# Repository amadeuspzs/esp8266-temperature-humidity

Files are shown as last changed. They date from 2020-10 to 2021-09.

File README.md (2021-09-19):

# esp8266-temperature-humidity

**Problem statement**:

> As a home-owner/renter I need to control multiple heating systems with room-by-room thermostats that I can move around for optimum measurements.

**Solution statement**:

> Hardware (ESP12F with Si7021 sensor) and software (Arduino) implementation of a WiFi MQTT temperature/humidity sensor with battery voltage monitoring and 9+ months rechargeable battery life. Designed for integration with [Home Assistant](https://www.home-assistant.io/).

See the [product website](https://amadeuspzs.github.io/esp8266-temperature-humidity/) for a summary.

Example output via Home Assistant

Example energy usage over startup and 4 measurements

## Prerequisites

1. An ESP8266 implementation like ESP-01, ESP-12F or NodeMCU
2. A <strike>DHT22 or</strike> Si7021 sensor
2. An MQTT server like [Mosquitto](https://mosquitto.org/)
3. 2.4GHz WiFi network with the ability to assign static IP addresses
4. Arduino IDE for flashing

## [Hardware](hardware/)

Tested on:

1. ESP-01 _lacks easy GPIO16 access for deep sleep_
2. ESP-12F **current preferred module**
3. NodeMCU _has power-hungry onboard components_

Tested with:

1. DHT22 _inefficient and low precision_
2. Si7021 **current preferred sensor**

Tested with:

1. 2xAA batteries _fine but unsustainable_
2. Generic JST Li-Ion battery **current preferred battery**

Tested with:

1. MCP1700 **current preferred regulator**
2. TPS62203 _high frequency switching too fiddly to implement stably_

End goal is to print the smallest PCB + battery package and 3D print a case for discrete deployment.

## [Software](software/)

Goal is to make the device last as long as possible on batteries.

## Energy performance

Current best energy usage is using the Si7021 sensor, measured using a [currentRanger](https://lowpowerlab.com/guide/currentranger/).

**Startup: `0.0789mAh`**

Startup

This includes initial connection to WiFi, sensor reading, publication, writing to RTC memory.

**Reading (no change): `0.0012mAh`**

No change

This shows the initial reading of RTC memory, sensor measurement, sleep and wake up to publish result.

**Reading (change): `0.0285mAh`**

Change

This shows the initial reading of RTC memory, sensor measurement, sleep and wake up to publish result.

**Energy estimates**

* Worst case (a reading every 10 minutes): `4.75mAh/day` this should last ~**9 months** on a 1200mAh battery.
* Better case (heuristically [50 readings a day](analysis/temperature.ipynb)): `2.19mAh/day` this should last **over a year** on a 1200mAh battery.

### Credits

* Many thanks to [Andy Bennett](http://twitter.com/databasescaling) for all the support and assistance throughout the projet
* Thanks to the [OpenEnergyMonitor Project](https://openenergymonitor.org/) for the tip on Si7021 sensor and low power inspirations.
* Thanks to the [LowPowerLab team](https://lowpowerlab.com/) for making the CurrentRanger and low power inspirations.

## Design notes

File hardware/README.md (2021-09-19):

# Hardware

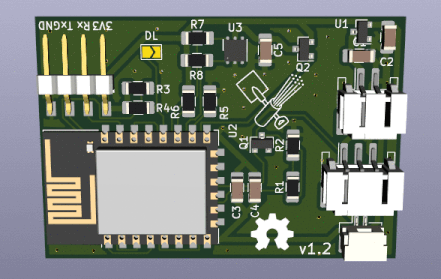
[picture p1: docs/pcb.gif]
PCB in 3D


## Battery powered

**Goal: run for 6 months+ using a battery.**

### Batteries

Device|Min voltage (V)|Stated voltage (V)|Max voltage (V)
---|---|---|---
[ESP-12F](http://wiki.ai-thinker.com/_media/esp8266/a014ps01.pdf)|3.0|3.3|3.6
[Li-Ion Cell](https://www.amazon.co.uk/XHDATA-Rechargeable-Intelligent-Protection-Environmental-BL-5C/dp/B0796L49J1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)|2.8|3.7|4.2
2 X AA Alkaline|2.8|3|3.3

Two options:

1. Regulate the Li-Ion voltage to 3.3V using e.g. [MCP1700](https://www.microchip.com/wwwproducts/en/MCP1700)
2. Run off alkaline batteries without regulator (unsustainable as not rechargeable)

##### Li-Ion cells (UK)

Battery|Cost (£)|Capacity (mAh)|Unit Cost (p/mAh)|Connector
---|---|---|---|---
[BL-5C](https://www.amazon.co.uk/XHDATA-Rechargeable-Intelligent-Protection-Environmental-BL-5C/dp/B0796L49J1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)|4.49|1500|0.30|None
[MakerFocus](https://www.ebay.co.uk/itm/4pcs-3-7V-1000mAh-Lipo-Batteries-with-Micro-JST-1-25-Plug-for-Arduino-Nodemcu/402439197613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)|3.49|1000|0.35|JST GH 1.25
[Generic](https://www.ebay.co.uk/itm/4Packs-1800mAh-3-7V-Lipo-Battery-USB-Charger-JST-Plug-for-RC-Quadcopter-Drone-UK/402483469522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)|4.75|1800|0.26|JST RCY (BEC)
**[Generic](https://www.ebay.co.uk/itm/3-7V-1200mAh-Lipo-Polymer-Rechargeable-Battery-JST-3P-PH-2-0mm-connector-603450/123751016161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)**|**2.59**|**1200**|**0.22**|**JST PH 3pin**
[Generic](https://www.ebay.co.uk/itm/3-7V-1200mAh-Lipo-rechargeable-Battery-603450-JST-1-25mm-2pin-plug-For-GPS-MP3/124254908489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)|2.00|1200|0.17|JST GH 1.25mm 2 pin
[CrazePony](https://www.amazon.co.uk/Crazepony-UK-1600mAh-battery-Connector-Quadcopter/dp/B07SPZXRWZ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)|5.50|1600|0.34|JST RCY (BEC)
[Adafruit LiPo](https://www.adafruit.com/product/1578)|6.00|500|1.20|JST PH
[Cool Components](https://coolcomponents.co.uk/products/lithium-polymer-battery-1000mah?_pos=7&_sid=3b7614679&_ss=r)|7.50|1000|0.75|JST PH
["LG" 18650](https://www.ebay.co.uk/itm/Genuine-LG-HG2-18650e-3000mAh-30A-3-7V-Rechargeable-Battery-With-Free-CASE/254800295445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)|5.49|3000|0.18|None - use case

##### Connectors

Connector|Spacing (mm)|Type|Cost (£)
---|---|---|---
[JST GH](https://www.aliexpress.com/item/33051405214.html?spm=2114.12057483.0.0.4016581aHOYzeO)|1.25|Right angle through hole|0.0009
JST RCY|
[JST PH 2pin](https://uk.farnell.com/jst-japan-solderless-terminals/b2b-ph-sm4-tb-lf-sn/connector-header-smt-2mm-2way/dp/9492534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)|2.0|Right angle PCB|0.45
**[JST PH 3pin](https://uk.farnell.com/jst-japan-solderless-terminals/b3b-ph-sm4-tb-lf-sn/connector-header-smt-2mm-3way/dp/9492542)**|**2.0**|**Right angle PCB**|**0.52**

### 3.3V Regulators

Regulator|Type|Quiescent Current (uA)|V<sub>in</sub> (V)|Max current (mA)|Package
---|---|---|---|---|---
[MCP1700](https://www.microchip.com/wwwproducts/en/MCP1700)|LDO|1.6|3.6-6|250|SOT-23
[TPS62203](https://www.ti.com/product/TPS62203)|Buck|15|3.6-6|300|SOT-23

### Sensors

Sensor|Package|Power up time (ms)|Read time (ms)|Active current (mA)|Standby current (uA)|Repeatability (RH%)|Repeatability (°C)
---|---|---|---|---|---|---|---
[DHT22](https://www.sparkfun.com/datasheets/Sensors/Temperature/DHT22.pdf)|Large|N/A|2000|1.5|50|1|0.2
[Si7021](https://www.silabs.com/documents/public/data-sheets/Si7021-A20.pdf)|DFN|18|10|0.15|0.06|0.2|0.08

Compare the current usage of both sensors (the initial section is reading RTC memory):

**DHT22:**

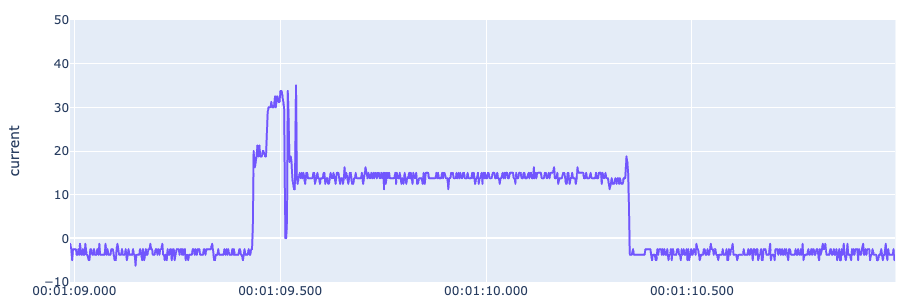
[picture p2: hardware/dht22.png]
DHT22


**Si7021:**

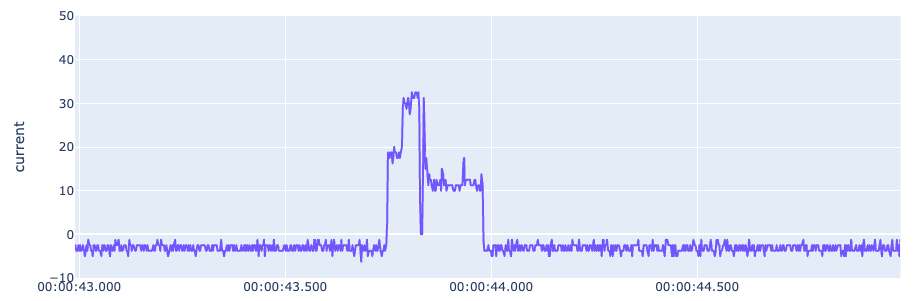
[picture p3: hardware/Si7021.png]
Si7021


The **Si7021** outperforms in both precision, accuracy, speed and current!

### Schematics

**Battery powered MCP1700 Si7021:**

Battery powered Si7021 v1.3

PCB

**Mains powered DHT22:**

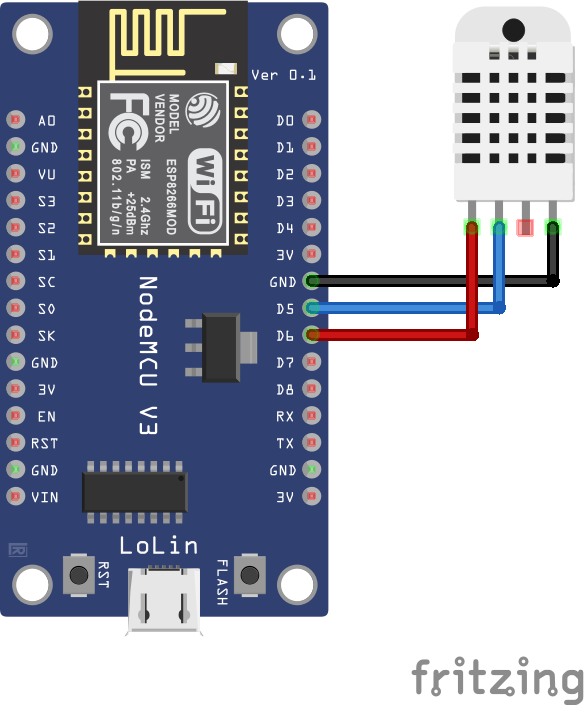
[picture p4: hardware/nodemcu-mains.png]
Mains powered DHT22


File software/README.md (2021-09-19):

# Software

Flashed using the Arduino IDE and Board Manager URL: http://arduino.esp8266.com/stable/package_esp8266com_index.json with "Generic ESP8266 Module" board.

There are two versions:

1. Mains-powered sketch
2. Battery-powered sketch, pushing every 10 minutes

Both require an MQTT server.

Additionally there is an [ADC calibration sketch](adc-calibration/) for more accurate battery health measurements.

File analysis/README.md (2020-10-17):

# Analysis

Various tools to analyse elements of the project with the aim to:

1. Maximise power efficiency
2. Understand heat transfer between rooms

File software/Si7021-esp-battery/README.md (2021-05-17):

# Battery-powered sketch

Low power version based on https://www.bakke.online/index.php/2017/05/21/reducing-wifi-power-consumption-on-esp8266-part-1/ and https://blog.voneicken.com/projects/low-power-wifi-intro/.

`WAKE_RF_DEFAULT` workaround thanks to https://github.com/esp8266/Arduino/issues/3072#issuecomment-288530130

Flashed using the Arduino IDE and Board Manager URL http://arduino.esp8266.com/stable/package_esp8266com_index.json with "Generic ESP8266 Module" board.

## Features

1. Uses `WAKE_RF_DISABLED` in deep sleep to shut down RF when not needed
2. Stores `BSSID` after connection to save scan time
3. Checks every X (10) minutes for change in temperature
4. If temperature change detected, checks for changes in humidity and Vbatt
5. Reboots with `WAKE_RF_DEFAULT` and publishes changes

## Flowchart

Flowchart

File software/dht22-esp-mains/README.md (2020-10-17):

# Mains-powered sketch

Features:

* USB powered via NodeMCU board
* Only publishes changes >= repeatability of sensor
* Checks every [X] minute(s)

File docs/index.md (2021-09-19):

# Low power WiFi temperature/humidity sensor

## Features

* 9 months+ runtime on a 1200mAh Li-Ion battery
* Highly accurate Si7021 temperature and humidity sensor
* Physical case with low impact on temperature (<0.05&deg;C)
* MQTT integration with e.g. Home Assistant directly over WiFi
* PH2, PH3 and GH2 connectors for range of Li-Ion batteries
* POGO programming header for quick flashing
* Battery voltage measurement for power management
* [Technical details available on Github](https://github.com/amadeuspzs/esp8266-temperature-humidity/)

## PCB

* No through-hole components for easy stacking on top of Li-Ion battery
* Two-layer, 50 mm x 34 mm
* [KiCad files](https://github.com/amadeuspzs/esp8266-temperature-humidity/tree/master/hardware/esp12f-si7021/)
* [Gerber files](https://github.com/amadeuspzs/esp8266-temperature-humidity/tree/master/hardware/esp12f-si7021/gerber)
* [Partial BoM](https://github.com/amadeuspzs/esp8266-temperature-humidity/tree/master/hardware/esp12f-si7021/esp12f-si7021_bom.csv)

## Software

* [Arduino files](https://github.com/amadeuspzs/esp8266-temperature-humidity/tree/master/software/Si7021-esp-battery)
* Update `config.h` with your settings
* Fine-tune `vbatt_calibration` for accurate battery voltage measurements

## Case

* 3D printed case: [STL](https://github.com/amadeuspzs/esp8266-temperature-humidity/tree/master/hardware/case_with_lid.stl), [SCAD](https://github.com/amadeuspzs/esp8266-temperature-humidity/tree/master/hardware/case_with_lid.scad)

Render of 3D printed case2

Photo of 3D printed case1

* Analysis shows latest case design (`case2`) only impacts temperature readings by `0.05`&deg;C, less than the sensor repeatability (`0.08`&deg;C):

Analysis of case impact

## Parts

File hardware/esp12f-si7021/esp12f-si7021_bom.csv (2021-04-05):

Reference | Quantity | Value | Footprint | Datasheet
C1 C2 | 2 | 1uF | Capacitor_SMD:C_1206_3216Metric_Pad1.42x1.75mm_HandSolder | ~
C3 C5 | 2 | 0.1uF | Capacitor_SMD:C_1206_3216Metric_Pad1.42x1.75mm_HandSolder | ~
C4 | 1 | 10uF | Capacitor_SMD:C_1206_3216Metric_Pad1.42x1.75mm_HandSolder | ~
J1 | 1 | JST PH3 | Connector_JST:JST_PH_S3B-PH-SM4-TB_1x03-1MP_P2.00mm_Horizontal | ~
J2 | 1 | UART | kicad-custom:PinHeader_1x4_P2.54mm_Horizontal_SMD | ~
J3 | 1 | JST PH2 | Connector_JST:JST_PH_S2B-PH-SM4-TB_1x02-1MP_P2.00mm_Horizontal | ~
J4 | 1 | JST GH2 | Connector_JST:JST_GH_SM02B-GHS-TB_1x02-1MP_P1.25mm_Horizontal | ~
JP1 | 1 | Download | Jumper:SolderJumper-2_P1.3mm_Open_TrianglePad1.0x1.5mm | ~
Q1 Q2 | 2 | BSS84 | Package_TO_SOT_SMD:SOT-23 | http://assets.nexperia.com/documents/data-sheet/BSS84.pdf
R1 | 1 | 330K | Resistor_SMD:R_1206_3216Metric_Pad1.42x1.75mm_HandSolder | ~
R2 | 1 | 100K | Resistor_SMD:R_1206_3216Metric_Pad1.42x1.75mm_HandSolder | ~
R3 R4 R5 R6 R7 R8 | 6 | 10K | Resistor_SMD:R_1206_3216Metric_Pad1.42x1.75mm_HandSolder | ~
U1 | 1 | MCP1700-3302E_SOT23 | Package_TO_SOT_SMD:SOT-23 | http://ww1.microchip.com/downloads/en/DeviceDoc/20001826D.pdf
U2 | 1 | ESP-12F | RF_Module:ESP-12E | http://wiki.ai-thinker.com/_media/esp8266/esp8266_series_modules_user_manual_v1.1.pdf
U3 | 1 | Si7021-A20 | Package_DFN_QFN:DFN-6-1EP_3x3mm_P1mm_EP1.5x2.4mm | https://www.silabs.com/documents/public/data-sheets/Si7021-A20.pdf

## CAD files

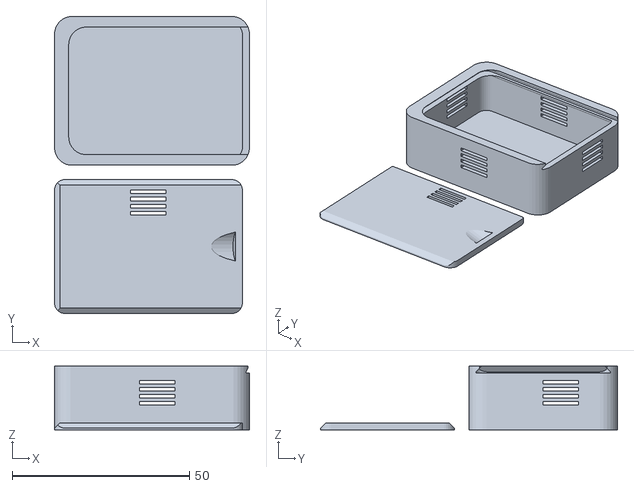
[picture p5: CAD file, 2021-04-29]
hardware/case_with_lid.stl
55.0 x 83.8 x 18.0

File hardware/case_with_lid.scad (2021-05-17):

// Remixed from https://www.thingiverse.com/thing:189264
// Todo: the rotation of the lid makes the lid vent alignment hard-coded; if you
// change the size of the box the vent won't necessarily remain aligned

wallThickness=2;

pcb_w = 34;   // PCB width
pcb_l = 50; // PCB length
pcb_h = 8; // PCB height, assembled
batt_w = 38;  // Battery width
batt_l = 51;  // Battery length
batt_h = 6;  // Battery height
overall_w = max(batt_w, pcb_w) + 2*wallThickness;
overall_l = max(batt_l, pcb_l) + 2*wallThickness;
overall_h = batt_h + pcb_h + 2*wallThickness;

itemsShown="both"; // [both,box,lid]
boxLength=overall_l;
boxWidth=overall_w;
boxHeight=overall_h;
cornerRadius=5;
bottomThickness=2;
lidThickness=2;
lidClearance=0.2;
lidEdgeThickness=0.5;
// Notch in the lid
withNotch=true; //[true:false]

sensor_pos_x = 24; // Sensor position
sensor_pos_lid_x = (overall_l - 1.5*sensor_pos_x) + wallThickness + lidEdgeThickness;

/* [Global] */
if (itemsShown=="box") showBox();
if (itemsShown=="lid") showLid();
if (itemsShown=="both"){showBox();showLid();}

module showLid(){
	translate ([0, -2*wallThickness, 0])
	roundBoxLid(l=boxLength-wallThickness,
				w=boxWidth-2*wallThickness-lidClearance,
				h=lidThickness,
				et=lidEdgeThickness,
				r=cornerRadius-wallThickness,
				notch=withNotch);
}

module showBox(){
	round_box(l=boxLength,
			  w=boxWidth,
			  h=boxHeight,
			  bt=bottomThickness,
			  wt=wallThickness,
			  lt=lidThickness,
			  r=cornerRadius);
}

module round_box(l=40,w=30,h=30,bt=2,wt=2,lt=2,r=5,){
	difference() {
		round_cube(l=l,w=w,h=h-lt,r=r);
		translate ([wt, wt, bt])
		round_cube(l=l-wt*2,w=w-wt*2,h=h,r=r-wt);
        // air holes
        translate([sensor_pos_x,0,7]) cube([10,3,1]);
        translate([sensor_pos_x,0,9]) cube([10,3,1]);
        translate([sensor_pos_x,0,11]) cube([10,3,1]);
        translate([sensor_pos_x,0,13]) cube([10,3,1]);
        translate([sensor_pos_x,boxWidth-(2*wallThickness),7]) cube([10,5,1]);
        translate([sensor_pos_x,boxWidth-(2*wallThickness),9]) cube([10,5,1]);
        translate([sensor_pos_x,boxWidth-(2*wallThickness),11]) cube([10,5,1]);
        translate([sensor_pos_x,boxWidth-(2*wallThickness),13]) cube([10,5,1]);
        translate([-wallThickness,boxWidth/2,7]) cube([5,10,1]);
        translate([-wallThickness,boxWidth/2,9]) cube([5,10,1]);
        translate([-wallThickness,boxWidth/2,11]) cube([5,10,1]);
        translate([-wallThickness,boxWidth/2,13]) cube([5,10,1]);
        translate([boxLength-wallThickness,boxWidth/2,7]) cube([5,10,1]);
        translate([boxLength-wallThickness,boxWidth/2,9]) cube([5,10,1]);
        translate([boxLength-wallThickness,boxWidth/2,11]) cube([5,10,1]);
        translate([boxLength-wallThickness,boxWidth/2,13]) cube([5,10,1]);
	}


	//use two box rims. one to make a slope to support the lid
	roundBoxRim();
	translate ([0, 0, -wt]) roundBoxRim();
}

module roundBoxRim(l=boxLength,
				   w=boxWidth,
				   h=boxHeight,
				   et=lidEdgeThickness,
				   r=cornerRadius,
				   wt=wallThickness,
				   lt=lidThickness){
	difference() {
		translate ([0, 0, h-lt])
		round_cube(l=l,w=w,h=lt,r=r);
		translate ([wt+lt,wt+lt-et*2,h-lt-0.1])
		round_cube(l=l*2,w=w-2*(wt+lt)+4*et,h=lt+0.2,r=r-wt+lt);

		//subtract out a lid to make the ledge
		translate ([wt, w-wt, h-lt-0.1])
		roundBoxLid(l=l*2,w=w-2*wt,h=lt+0.1,wt=wt,t=lt,et=0.5,r=r-wt,notch=false);
	}
}

module roundBoxLid(l=40,w=30,h=3,wt=2,t=2,et=0.5,r=5,notch=true){
	translate ([l, 0, 0])
	rotate (a = [0, 0, 180])

	difference(){

		round_cube(l=l,w=w,h=h,t=t,r=r);

		translate ([-1, 0, et]) rotate (a = [45, 0, 0])  cube (size = [l+2, h*2, h*2]);
		translate ([-1, w, et]) rotate (a = [45, 0, 0])  cube (size = [l+2, h*2, h*2]);
		translate ([l, -1, et]) rotate (a = [45, 0, 90]) cube (size = [w+2, h*2, h*2]);
		if (notch==true){
			translate([2,w/2,h+0.001]) thumbNotch(10/2,72,t);
		}
        translate([sensor_pos_lid_x,wallThickness+1,-lidThickness]) cube([10,1,lidThickness*3]);
        translate([sensor_pos_lid_x,wallThickness+3,-lidThickness]) cube([10,1,lidThickness*3]);
        translate([sensor_pos_lid_x,wallThickness+5,-lidThickness]) cube([10,1,lidThickness*3]);
        translate([sensor_pos_lid_x,wallThickness+7,-lidThickness]) cube([10,1,lidThickness*3]);
	}



}

module thumbNotch(
	thumbR=12/2,
	angle=72,
	notchHeight=2){

	size=10*thumbR;

	rotate([0,0,90])
	difference(){
		translate([0,
					(thumbR*sin(angle)-notchHeight)/tan(angle),
					 thumbR*sin(angle)-notchHeight])
		rotate([angle,0,0])
		cylinder(r=thumbR,h=size,$fn=30);

		translate([-size,-size,0])
		cube(size*2);
	}
}

module round_cube(l=40,w=30,h=20,r=5,$fn=30){
	hull(){
		translate ([r, r, 0]) cylinder (h = h, r=r);
		translate ([r, w-r, 0]) cylinder (h = h, r=r);
		translate ([l-r,w-r, 0]) cylinder (h = h, r=r);
		translate ([l-r, r, 0]) cylinder (h = h, r=r);
	}
}

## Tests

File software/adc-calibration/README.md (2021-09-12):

# ADC calibration

The ESP12F (esp8266) ADC has a built-in voltage reference of ~1.0V.

The circuit contains a voltage divider to convert a maximum 4.2V input (LiPo max voltage) to 1.0V.

The resulting measurement is used to report battery voltage via MQTT.

Both the ADC voltage reference and voltage divider values will vary from component to component.

The stock code assumes an ideal value for both:

```arduino
// Ideal ADC and voltage divider behaviour
// is 4.2/1024.0
// For accurate battery voltage measurements
// use an accurate voltage input, measure ADC
// and replace values below (assumes linear response)
#define vbatt_calibration 4.2/1024.0
```

ie. for a 4.2V input, an ADC reading of 1024.

In reality, you will want to use a known voltage, measure the ADC value and update `vbatt_calibration` to match.

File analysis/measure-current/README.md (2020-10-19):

# Measure Current

1. [Adafruit INA260 board](https://www.adafruit.com/product/4226)
2. Sparkfun Pro Micro (32U4), serial output saving to `csv`
3. [Jupyter Notebook](measure-current.ipynb)

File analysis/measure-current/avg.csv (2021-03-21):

Timestamp | Amps
2021-02-22 12:08:58.410521 | 2.659e-05
2021-02-22 12:08:58.411098 | 3.626e-05
2021-02-22 12:08:58.411588 | 3.949e-05
2021-02-22 12:08:58.412006 | 4.392e-05
2021-02-22 12:08:58.412436 | 3.949e-05
2021-02-22 12:08:58.412718 | 3.022e-05
2021-02-22 12:08:58.413000 | 2.901e-05
2021-02-22 12:08:58.413251 | 2.901e-05
2021-02-22 12:08:58.413499 | 2.7e-05
2021-02-22 12:08:58.413742 | 2.458e-05
2021-02-22 12:08:58.414354 | 2.377e-05
2021-02-22 12:08:58.414681 | 2.982e-05
2021-02-22 12:08:58.414895 | 3.223e-05
2021-02-22 12:08:58.415414 | 2.901e-05
2021-02-22 12:08:58.415779 | 2.861e-05
2021-02-22 12:08:58.416037 | 2.821e-05
2021-02-22 12:08:58.416561 | 3.183e-05
2021-02-22 12:08:58.416849 | 3.062e-05
2021-02-22 12:08:58.417328 | 2.982e-05
2021-02-22 12:08:58.417609 | 3.143e-05
2021-02-22 12:08:58.417932 | 3.264e-05
2021-02-22 12:08:58.418476 | 3.103e-05
2021-02-22 12:08:58.418766 | 2.941e-05
2021-02-22 12:08:58.419393 | 2.941e-05
2021-02-22 12:08:58.419754 | 2.901e-05
2021-02-22 12:08:58.420023 | 3.022e-05
2021-02-22 12:08:58.420528 | 2.982e-05
2021-02-22 12:08:58.420854 | 2.941e-05
2021-02-22 12:08:58.421329 | 2.78e-05
2021-02-22 12:08:58.421782 | 2.74e-05
2021-02-22 12:08:58.422524 | 2.458e-05
2021-02-22 12:08:58.422875 | 2.538e-05
2021-02-22 12:08:58.423068 | 2.377e-05
2021-02-22 12:08:58.423333 | 2.74e-05
2021-02-22 12:08:58.423578 | 3.143e-05
2021-02-22 12:08:58.423899 | 3.304e-05
2021-02-22 12:08:58.424474 | 2.941e-05
2021-02-22 12:08:58.424862 | 2.901e-05
2021-02-22 12:08:58.425378 | 3.062e-05
2021-02-22 12:08:58.425774 | 3.223e-05
2021-02-22 12:08:58.426050 | 3.143e-05
2021-02-22 12:08:58.426314 | 2.901e-05
2021-02-22 12:08:58.426645 | 3.022e-05
2021-02-22 12:08:58.427454 | 3.103e-05
2021-02-22 12:08:58.427944 | 3.143e-05
2021-02-22 12:08:58.428519 | 2.982e-05
2021-02-22 12:08:58.429022 | 2.498e-05
2021-02-22 12:08:58.429362 | 2.982e-05
2021-02-22 12:08:58.429678 | 2.861e-05
2021-02-22 12:08:58.429909 | 2.901e-05
2021-02-22 12:08:58.430217 | 2.861e-05
2021-02-22 12:08:58.430690 | 2.861e-05
2021-02-22 12:08:58.431209 | 3.264e-05
2021-02-22 12:08:58.431598 | 3.183e-05
2021-02-22 12:08:58.431981 | 3.505e-05
2021-02-22 12:08:58.432427 | 3.465e-05
2021-02-22 12:08:58.432774 | 3.183e-05
2021-02-22 12:08:58.433202 | 3.022e-05
2021-02-22 12:08:58.433432 | 2.659e-05
2021-02-22 12:08:58.433893 | 2.538e-05
2021-02-22 12:08:58.434432 | 2.538e-05
2021-02-22 12:08:58.435092 | 2.7e-05
2021-02-22 12:08:58.435550 | 2.941e-05
2021-02-22 12:08:58.435795 | 2.982e-05
2021-02-22 12:08:58.436011 | 3.183e-05
2021-02-22 12:08:58.436272 | 3.385e-05
2021-02-22 12:08:58.436470 | 3.465e-05
2021-02-22 12:08:58.436743 | 3.143e-05
2021-02-22 12:08:58.437096 | 2.982e-05
2021-02-22 12:08:58.437675 | 2.861e-05
2021-02-22 12:08:58.437981 | 2.941e-05
2021-02-22 12:08:58.438290 | 2.861e-05
2021-02-22 12:08:58.438616 | 3.022e-05
2021-02-22 12:08:58.439024 | 2.74e-05
2021-02-22 12:08:58.439483 | 2.901e-05
2021-02-22 12:08:58.439783 | 2.821e-05
2021-02-22 12:08:58.440136 | 3.223e-05
2021-02-22 12:08:58.440543 | 3.143e-05
2021-02-22 12:08:58.441063 | 2.7e-05
2021-02-22 12:08:58.441449 | 2.498e-05
2021-02-22 12:08:58.441828 | 2.538e-05
2021-02-22 12:08:58.442250 | 3.022e-05
2021-02-22 12:08:58.442620 | 3.264e-05
2021-02-22 12:08:58.442983 | 3.586e-05
2021-02-22 12:08:58.443280 | 3.022e-05
2021-02-22 12:08:58.443781 | 2.982e-05
2021-02-22 12:08:58.444130 | 3.062e-05
2021-02-22 12:08:58.444344 | 2.901e-05
2021-02-22 12:08:58.444813 | 3.022e-05
2021-02-22 12:08:58.445258 | 2.901e-05
2021-02-22 12:08:58.445603 | 2.7e-05
2021-02-22 12:08:58.445861 | 2.619e-05
2021-02-22 12:08:58.446370 | 2.821e-05
2021-02-22 12:08:58.446799 | 2.78e-05
2021-02-22 12:08:58.447115 | 2.74e-05
2021-02-22 12:08:58.447318 | 2.74e-05
2021-02-22 12:08:58.447745 | 3.103e-05
2021-02-22 12:08:58.448250 | 3.304e-05
2021-02-22 12:08:58.448615 | 3.143e-05
2021-02-22 12:08:58.448861 | 2.538e-05
2021-02-22 12:08:58.449252 | 3.022e-05
2021-02-22 12:08:58.449799 | 2.901e-05
2021-02-22 12:08:58.450040 | 3.062e-05
2021-02-22 12:08:58.450412 | 3.183e-05
2021-02-22 12:08:58.450852 | 3.062e-05
2021-02-22 12:08:58.451320 | 3.223e-05
2021-02-22 12:08:58.451718 | 3.626e-05
2021-02-22 12:08:58.452052 | 3.022e-05
2021-02-22 12:08:58.452375 | 2.78e-05
2021-02-22 12:08:58.452847 | 2.7e-05
2021-02-22 12:08:58.453241 | 2.821e-05
2021-02-22 12:08:58.453516 | 2.901e-05
2021-02-22 12:08:58.453938 | 2.78e-05
2021-02-22 12:08:58.454639 | 2.861e-05
2021-02-22 12:08:58.454902 | 2.659e-05
2021-02-22 12:08:58.455172 | 3.022e-05
2021-02-22 12:08:58.455661 | 3.103e-05
2021-02-22 12:08:58.456014 | 3.505e-05
2021-02-22 12:08:58.456241 | 3.505e-05
2021-02-22 12:08:58.456628 | 3.385e-05
2021-02-22 12:08:58.457134 | 3.264e-05
2021-02-22 12:08:58.457602 | 3.264e-05
2021-02-22 12:08:58.457853 | 2.982e-05
2021-02-22 12:08:58.458300 | 2.74e-05
2021-02-22 12:08:58.458743 | 2.498e-05
2021-02-22 12:08:58.459156 | 2.377e-05
2021-02-22 12:08:58.459517 | 2.659e-05
2021-02-22 12:08:58.459776 | 2.619e-05
2021-02-22 12:08:58.460312 | 2.901e-05
2021-02-22 12:08:58.460669 | 2.78e-05
2021-02-22 12:08:58.461111 | 2.821e-05
2021-02-22 12:08:58.461330 | 3.223e-05
2021-02-22 12:08:58.461782 | 3.344e-05
2021-02-22 12:08:58.462180 | 3.505e-05
2021-02-22 12:08:58.462602 | 3.103e-05
2021-02-22 12:08:58.463041 | 2.458e-05
2021-02-22 12:08:58.463419 | 2.377e-05
2021-02-22 12:08:58.463715 | 2.377e-05
2021-02-22 12:08:58.464242 | 2.337e-05
2021-02-22 12:08:58.464603 | 2.579e-05
2021-02-22 12:08:58.465097 | 2.7e-05
2021-02-22 12:08:58.465310 | 3.103e-05
2021-02-22 12:08:58.465636 | 3.183e-05
2021-02-22 12:08:58.466180 | 3.143e-05
2021-02-22 12:08:58.466435 | 2.941e-05
2021-02-22 12:08:58.466801 | 2.821e-05
2021-02-22 12:08:58.467173 | 3.062e-05
2021-02-22 12:08:58.467680 | 3.264e-05
2021-02-22 12:08:58.467962 | 3.103e-05
2021-02-22 12:08:58.468430 | 3.103e-05
2021-02-22 12:08:58.468639 | 3.143e-05
2021-02-22 12:08:58.469122 | 2.982e-05
2021-02-22 12:08:58.469570 | 3.143e-05
2021-02-22 12:08:58.469815 | 3.344e-05
2021-02-22 12:08:58.470225 | 3.183e-05
2021-02-22 12:08:58.470596 | 2.821e-05
2021-02-22 12:08:58.471467 | 2.861e-05
2021-02-22 12:08:58.471705 | 2.7e-05
2021-02-22 12:08:58.471907 | 2.78e-05
2021-02-22 12:08:58.472161 | 2.74e-05
2021-02-22 12:08:58.472603 | 3.304e-05
2021-02-22 12:08:58.473277 | 3.062e-05
2021-02-22 12:08:58.473570 | 3.022e-05
2021-02-22 12:08:58.473772 | 2.901e-05
2021-02-22 12:08:58.474240 | 2.982e-05
2021-02-22 12:08:58.474603 | 2.861e-05
2021-02-22 12:08:58.474940 | 3.062e-05
2021-02-22 12:08:58.475342 | 3.546e-05
2021-02-22 12:08:58.475752 | 3.465e-05
2021-02-22 12:08:58.476177 | 3.062e-05
2021-02-22 12:08:58.476515 | 2.458e-05
2021-02-22 12:08:58.477155 | 2.659e-05
2021-02-22 12:08:58.477453 | 2.498e-05
2021-02-22 12:08:58.477680 | 2.74e-05
2021-02-22 12:08:58.478225 | 2.901e-05
2021-02-22 12:08:58.478479 | 3.304e-05
2021-02-22 12:08:58.478879 | 3.223e-05
2021-02-22 12:08:58.479387 | 3.425e-05
2021-02-22 12:08:58.479627 | 2.901e-05
2021-02-22 12:08:58.480252 | 2.579e-05
2021-02-22 12:08:58.480657 | 2.498e-05
2021-02-22 12:08:58.481084 | 2.377e-05
2021-02-22 12:08:58.481496 | 2.297e-05
2021-02-22 12:08:58.481861 | 2.74e-05
2021-02-22 12:08:58.482152 | 3.022e-05
2021-02-22 12:08:58.482400 | 3.062e-05
2021-02-22 12:08:58.482891 | 2.901e-05
2021-02-22 12:08:58.483370 | 2.74e-05
2021-02-22 12:08:58.483673 | 3.103e-05
2021-02-22 12:08:58.483980 | 3.062e-05
2021-02-22 12:08:58.484429 | 3.183e-05
2021-02-22 12:08:58.484818 | 3.143e-05
2021-02-22 12:08:58.485279 | 2.901e-05
2021-02-22 12:08:58.485795 | 2.659e-05
2021-02-22 12:08:58.486179 | 2.861e-05
2021-02-22 12:08:58.486459 | 2.982e-05
2021-02-22 12:08:58.486753 | 2.901e-05
2021-02-22 12:08:58.487096 | 2.78e-05
2021-02-22 12:08:58.487606 | 2.659e-05
2021-02-22 12:08:58.487936 | 2.297e-05
2021-02-22 12:08:58.488376 | 2.821e-05
2021-02-22 12:08:58.488594 | 2.7e-05
2021-02-22 12:08:58.489031 | 3.062e-05
2021-02-22 12:08:58.489398 | 3.264e-05
2021-02-22 12:08:58.489799 | 3.385e-05
2021-02-22 12:08:58.490503 | 3.546e-05
2021-02-22 12:08:58.490853 | 3.505e-05
2021-02-22 12:08:58.491124 | 3.344e-05
2021-02-22 12:08:58.491421 | 3.143e-05
2021-02-22 12:08:58.491836 | 2.901e-05
2021-02-22 12:08:58.492242 | 2.538e-05
2021-02-22 12:08:58.492529 | 2.659e-05
2021-02-22 12:08:58.492930 | 3.062e-05
2021-02-22 12:08:58.493500 | 2.7e-05
2021-02-22 12:08:58.493833 | 2.941e-05
2021-02-22 12:08:58.494308 | 3.425e-05
2021-02-22 12:08:58.494642 | 3.385e-05
2021-02-22 12:08:58.495018 | 3.143e-05
2021-02-22 12:08:58.495539 | 3.062e-05
2021-02-22 12:08:58.495982 | 2.901e-05
2021-02-22 12:08:58.496452 | 2.861e-05
2021-02-22 12:08:58.496843 | 2.74e-05
2021-02-22 12:08:58.497371 | 2.498e-05
2021-02-22 12:08:58.497679 | 2.458e-05
2021-02-22 12:08:58.498012 | 2.579e-05
2021-02-22 12:08:58.498363 | 2.7e-05
2021-02-22 12:08:58.498663 | 3.022e-05
2021-02-22 12:08:58.498899 | 3.304e-05
2021-02-22 12:08:58.499298 | 3.505e-05
2021-02-22 12:08:58.499618 | 2.901e-05
2021-02-22 12:08:58.500096 | 2.74e-05
2021-02-22 12:08:58.500459 | 2.74e-05
2021-02-22 12:08:58.500833 | 3.103e-05
2021-02-22 12:08:58.501178 | 3.385e-05
2021-02-22 12:08:58.501469 | 3.223e-05
2021-02-22 12:08:58.502058 | 2.74e-05
2021-02-22 12:08:58.502436 | 2.74e-05
2021-02-22 12:08:58.502847 | 2.861e-05
2021-02-22 12:08:58.503276 | 3.103e-05
2021-02-22 12:08:58.525275 | 2.619e-05
2021-02-22 12:08:58.525888 | 3.062e-05
2021-02-22 12:08:58.526315 | 2.901e-05
2021-02-22 12:08:58.526997 | 2.78e-05
2021-02-22 12:08:58.527455 | 3.062e-05
2021-02-22 12:08:58.527992 | 2.74e-05
2021-02-22 12:08:58.528565 | 2.579e-05
2021-02-22 12:08:58.529059 | 2.982e-05
2021-02-22 12:08:58.529379 | 2.861e-05
2021-02-22 12:08:58.529684 | 2.982e-05
2021-02-22 12:08:58.529930 | 2.901e-05
2021-02-22 12:08:58.530311 | 2.74e-05
2021-02-22 12:08:58.530586 | 2.941e-05
2021-02-22 12:08:58.530968 | 3.223e-05
2021-02-22 12:08:58.531565 | 3.546e-05
2021-02-22 12:08:58.532173 | 3.062e-05
2021-02-22 12:08:58.532779 | 3.385e-05
2021-02-22 12:08:58.533279 | 2.861e-05
2021-02-22 12:08:58.533605 | 3.223e-05
2021-02-22 12:08:58.534119 | 3.062e-05
2021-02-22 12:08:58.534409 | 3.264e-05
2021-02-22 12:08:58.534727 | 2.941e-05
2021-02-22 12:08:58.534946 | 3.143e-05
2021-02-22 12:08:58.535416 | 3.747e-05
2021-02-22 12:08:58.535804 | 3.264e-05
2021-02-22 12:08:58.536137 | 3.143e-05
2021-02-22 12:08:58.536453 | 3.022e-05
2021-02-22 12:08:58.537033 | 3.103e-05
2021-02-22 12:08:58.537314 | 2.821e-05
2021-02-22 12:08:58.537897 | 2.74e-05
2021-02-22 12:08:58.538598 | 2.659e-05
2021-02-22 12:08:58.538982 | 2.377e-05
2021-02-22 12:08:58.539337 | 2.216e-05
2021-02-22 12:08:58.539551 | 2.377e-05
2021-02-22 12:08:58.539893 | 2.901e-05
2021-02-22 12:08:58.540182 | 2.982e-05
2021-02-22 12:08:58.540581 | 2.861e-05
2021-02-22 12:08:58.540809 | 3.385e-05
2021-02-22 12:08:58.541078 | 3.344e-05
2021-02-22 12:08:58.541386 | 3.264e-05
2021-02-22 12:08:58.541690 | 3.304e-05
2021-02-22 12:08:58.541865 | 2.74e-05
2021-02-22 12:08:58.542233 | 2.74e-05
2021-02-22 12:08:58.542551 | 2.538e-05
2021-02-22 12:08:58.542892 | 2.659e-05
2021-02-22 12:08:58.543203 | 2.579e-05
2021-02-22 12:08:58.543704 | 2.861e-05
2021-02-22 12:08:58.544014 | 2.941e-05
2021-02-22 12:08:58.544327 | 3.062e-05
2021-02-22 12:08:58.544784 | 3.103e-05
2021-02-22 12:08:58.544989 | 3.022e-05
2021-02-22 12:08:58.545192 | 2.901e-05
2021-02-22 12:08:58.545436 | 3.062e-05
2021-02-22 12:08:58.545758 | 2.901e-05
2021-02-22 12:08:58.546189 | 2.7e-05
2021-02-22 12:08:58.546479 | 3.022e-05
2021-02-22 12:08:58.546862 | 3.022e-05
2021-02-22 12:08:58.547093 | 3.425e-05
2021-02-22 12:08:58.547367 | 3.062e-05
2021-02-22 12:08:58.547646 | 2.982e-05
2021-02-22 12:08:58.547859 | 2.941e-05
2021-02-22 12:08:58.548363 | 2.941e-05
2021-02-22 12:08:58.548614 | 2.78e-05
2021-02-22 12:08:58.549235 | 2.78e-05
2021-02-22 12:08:58.549611 | 2.7e-05
2021-02-22 12:08:58.549980 | 2.579e-05
2021-02-22 12:08:58.550294 | 2.659e-05
2021-02-22 12:08:58.550532 | 3.183e-05
2021-02-22 12:08:58.551100 | 3.586e-05
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

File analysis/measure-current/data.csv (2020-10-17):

timestamp | current | voltage
4 | 0.00 | 5030.00
6 | 1.25 | 5031.25
8 | 0.00 | 5031.25
10 | 0.00 | 5028.75
12 | 0.00 | 5028.75
14 | 1.25 | 5030.00
16 | 0.00 | 5030.00
18 | 1.25 | 5031.25
20 | 0.00 | 5030.00
22 | 0.00 | 5026.25
24 | 1.25 | 5026.25
26 | 2.50 | 5027.50
29 | 2.50 | 5030.00
31 | 0.00 | 5031.25
33 | 2.50 | 5031.25
35 | 1.25 | 5030.00
37 | 1.25 | 5027.50
39 | 0.00 | 5028.75
41 | 1.25 | 5030.00
44 | 1.25 | 5030.00
46 | 0.00 | 5030.00
48 | 0.00 | 5028.75
50 | 2.50 | 5027.50
52 | 1.25 | 5027.50
54 | 1.25 | 5031.25
56 | 1.25 | 5031.25
58 | 2.50 | 5030.00
60 | 1.25 | 5027.50
63 | 1.25 | 5027.50
65 | 2.50 | 5028.75
67 | 2.50 | 5030.00
69 | 1.25 | 5031.25
71 | 1.25 | 5030.00
73 | 1.25 | 5028.75
75 | 2.50 | 5027.50
77 | 1.25 | 5030.00
79 | 0.00 | 5031.25
81 | 0.00 | 5030.00
83 | 1.25 | 5028.75
86 | 0.00 | 5028.75
88 | 1.25 | 5027.50
90 | 0.00 | 5031.25
92 | 1.25 | 5031.25
94 | 1.25 | 5030.00
96 | 0.00 | 5027.50
99 | 0.00 | 5027.50
101 | 0.00 | 5028.75
103 | 2.50 | 5028.75
105 | 2.50 | 5031.25
107 | 1.25 | 5030.00
109 | 1.25 | 5027.50
111 | 1.25 | 5028.75
113 | 1.25 | 5030.00
115 | 1.25 | 5032.50
118 | 0.00 | 5031.25
120 | -1.25 | 5030.00
122 | 1.25 | 5027.50
124 | 1.25 | 5028.75
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

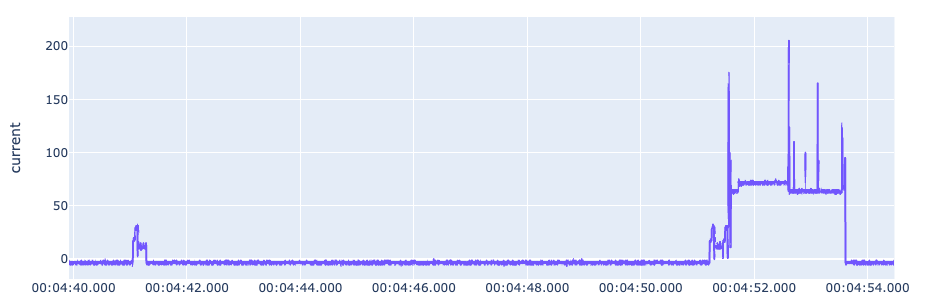
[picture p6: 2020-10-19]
analysis/measure-current/readings.png

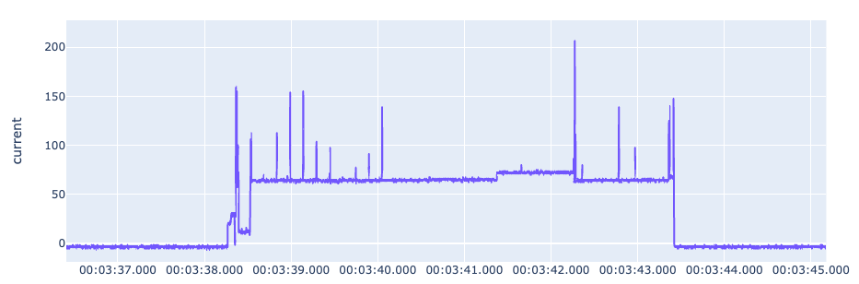
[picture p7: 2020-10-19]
analysis/measure-current/startup.png

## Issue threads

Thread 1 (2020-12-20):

v1.1

amadeuspzs, 2020-12-20:
- [x] Transistor switch for sensor, not directly switched via GPIO
- [x] Use ADC with voltage divider for sensing battery voltage, not built-in Vcc functionality
- [x] Match footprint of regulator on PCB

Closed 2021-02-20.

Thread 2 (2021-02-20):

v1.2

amadeuspzs, 2021-02-20:
- [x] Better jumper solution for download mode
- [x] Remove TPS footprint
- [x] Add other JST connectors for more battery options

Closed 2021-02-22.

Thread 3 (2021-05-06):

Vbatt precision poor

amadeuspzs, 2021-05-06:
ADC sucks. Check out http://esp8266-projects.org/2016/08/esp8266-internal-adc-2-the-easy-way-example/ which may require individual calibration per sensor?

amadeuspzs, 2021-05-18:
Now throwaway first reading and improves with manual calibration of `vref`

Closed 2021-05-18.

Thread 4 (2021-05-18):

PCB v1.3

amadeuspzs, 2021-05-18:
- [ ] Use Pogo pins for flashing
- [ ] Figure out clever way of entering download mode easily
- [ ] Consider adding reset

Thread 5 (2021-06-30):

Assembled Hardware?

msoose, 2021-06-30:
The hardware you've designed here is exactly what I'm looking for to complete a project.

Curiously, do you have this printed and assembled by a 'factory' or are you doing it by hand?

amadeuspzs, 2021-07-01:
Hi @msoose I print it with jlcpcb.com which is really straightforward.

I've then hand soldered the boards (the QFN package for the Si7021 is a little tricky and an earlier PCB design had extended pads to help - I will add this back in in future, but you can still hand solder the current PCB).

I've also rigged up a clothes iron to solder with a stencil (also from jlcpcb) and paste which works really well: https://twitter.com/amadeuspzs/status/1372111453885505539

I looked into a full assembly but didn't find a supplier with all the components I've selected. In future I might start with their components first if I want to scale up (e.g. https://jlcpcb.com/parts)

Closed 2021-07-12.

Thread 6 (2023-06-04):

Current consumption in idle mode

Portia-Lin, 2023-06-04:
You get great battery life from a single charge. I am also working on a similar device and I have my own implementation ideas for this. I looked through your code and didn't see a command to put the esp8266 to deepsleep mode. Maybe I was careless. How did you manage to get the esp8266 to work for so long from battery?
Maybe I would still ask your advice. I have several sensors on the I2C line and a flash card on the SPI line. I am going to use the esp8266 deepsleep mode and turn off all devices when the esp8266 sleeps. I want to use a mosfet, but what is better to cut, VCC or GND? P-channel or N-channel mosfet to precisely avoid current leakage, for example on the I2C line.

Portia-Lin, 2023-06-04:
I realized. I was just looking at the wrong code, now I see the deepsleep call. After the experiments, I had another question. I'm using an ESP-12F and it draws 120μA at 3.3V after going to sleep. This is after the voltage stabilizer. Why such a big value? I don't use anything else. Only ESP-12F module The datasheet indicates a consumption of 20 μA.

amadeuspzs, 2023-06-06:
What voltage stabilizer are you using? It will have a latent draw itself.

Also what are you using to measure current? At these ranges current measurement can be a little inaccurate.

Portia-Lin, 2023-06-06:
I use an AMS1117 stabilizer, but I measure the current consumption after it. After the power stabilizer, a 100 ohm resistor is placed in the power circuit gap. When starting the esp8266 I short the resistor. After switching to sleep mode, I remove the jumper from the resistor and measure the voltage drop across it. I calculate current consumption according to Ohm's law. Yesterday I picked up another ESP12F instead of the previous one. Its consumption in sleep mode during this experiment was calculated at 17 μA.
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

amadeuspzs, 2023-06-13:
With a 100R current sense resistor you're going to have a 33mA load from the resistor itself?

I would use a high accuracy and much smaller resistor:
https://components101.com/articles/what-is-current-sense-resistors-types-specifications-and-selection

For this project I used a https://lowpowerlab.com/guide/currentranger/ which handled all this for me.

Do you want to measure power consumption after the regulator? In my case I was interested in battery life, so I measured power consumption before the regulator as that is what was being drawn from the battery.

Also, I have found that energy usage does depend on distance to wifi access point - the further away/weaker the signal, the higher the energy usage.

Portia-Lin, 2023-06-14:
No, the current will not be 33mA. According to Kirchhoff's law, the current in a series power supply chain flows uniformly. I got a voltage drop of 12mV on the shunt resistor. According to Ohm's law: I = U / R = 0.012 / 100 = 120 μA. My voltage regulator is not suitable for battery power, it has a large voltage drop. I'm waiting for the MCP1700-3302 to arrive. I don't have them yet, so I measure after the stabilizer. Although according to Kirchhoff's law, the current in the series circuit is the same, as I said, so maybe my voltage regulator is introducing inaccuracies? But when using another ESP12 module in the same circuit, the discharged current is 16 μA. After searching the internet, I noticed that some users also encountered high current consumption of the ESP8266 in deep sleep mode. But unfortunately, no one could solve this problem...

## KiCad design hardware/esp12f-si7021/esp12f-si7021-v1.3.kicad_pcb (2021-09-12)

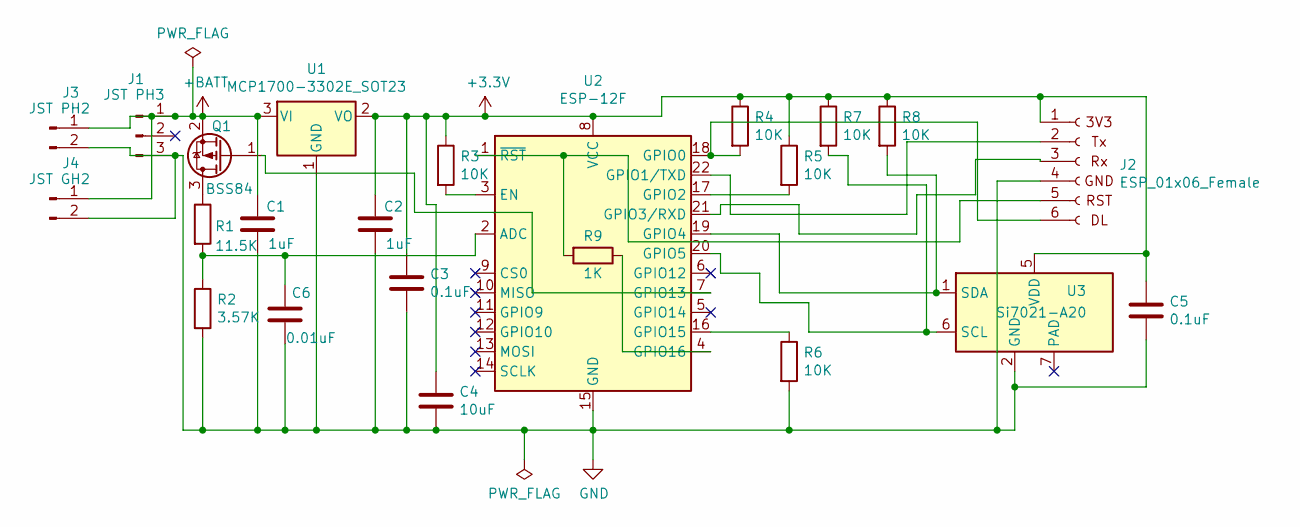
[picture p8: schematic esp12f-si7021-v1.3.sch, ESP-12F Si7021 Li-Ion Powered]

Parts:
C1, C2: 1uF; C_1206_3216Metric_Pad1.33x1.80mm_HandSolder
C3, C5: 0.1uF; C_1206_3216Metric_Pad1.33x1.80mm_HandSolder
C4: 10uF; C_1206_3216Metric_Pad1.33x1.80mm_HandSolder
C6: 0.01uF; C_1206_3216Metric_Pad1.33x1.80mm_HandSolder
J1: JST PH3; JST_PH_S3B-PH-SM4-TB_1x03-1MP_P2.00mm_Horizontal
J2: ESP_01x06_Female; 6-pogo-female
J3: JST PH2; JST_PH_S2B-PH-SM4-TB_1x02-1MP_P2.00mm_Horizontal
J4: JST GH2; JST_GH_SM02B-GHS-TB_1x02-1MP_P1.25mm_Horizontal
Q1: BSS84; SOT-23
R1: 11.5K; R_1206_3216Metric_Pad1.30x1.75mm_HandSolder
R2: 3.57K; R_1206_3216Metric_Pad1.30x1.75mm_HandSolder
R3, R4, R5, R6, R7, R8: 10K; R_1206_3216Metric_Pad1.30x1.75mm_HandSolder
R9: 1K; R_1206_3216Metric_Pad1.30x1.75mm_HandSolder
U1: MCP1700-3302E_SOT23; SOT-23
U2: ESP-12F; ESP-12E
U3: Si7021-A20; DFN-6-1EP_3x3mm_P1mm_EP1.5x2.4mm-HANDSOLDER

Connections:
+3V3: C2.1, C3.1, C4.1, C5.1, J2.1, R3.1, R4.1, R5.1, R7.1, R8.1, U1.2 (VO), U2.8 (VCC), U3.5 (VDD)
+BATT: C1.1, J1.1, J3.1, J4.1, Q1.2 (S), U1.3 (VI)
GND: C1.2, C2.2, C3.2, C4.2, C5.2, C6.2, J1.3, J2.4, J3.2, J4.2, R2.2, R6.2, U1.1 (GND), U2.15 (GND), U3.2 (GND)
unnamed: C6.1, R1.2, R2.1, U2.2 (ADC)
unnamed: J2.2, U2.22 (GPIO1/TXD)
unnamed: J2.3, U2.21 (GPIO3/RXD)
unnamed: J2.5, R9.2, U2.1 (~RST)
unnamed: J2.6, R4.2, U2.18 (GPIO0)
unnamed: Q1.1 (G), U2.7 (GPIO13)
unnamed: Q1.3 (D), R1.1
unnamed: R3.2, U2.3 (EN)
unnamed: R5.2, U2.17 (GPIO2)
unnamed: R6.1, U2.16 (GPIO15)
unnamed: R7.2, U2.20 (GPIO5), U3.6 (SCL)
unnamed: R8.2, U2.19 (GPIO4), U3.1 (SDA)
unnamed: R9.1, U2.4 (GPIO16)

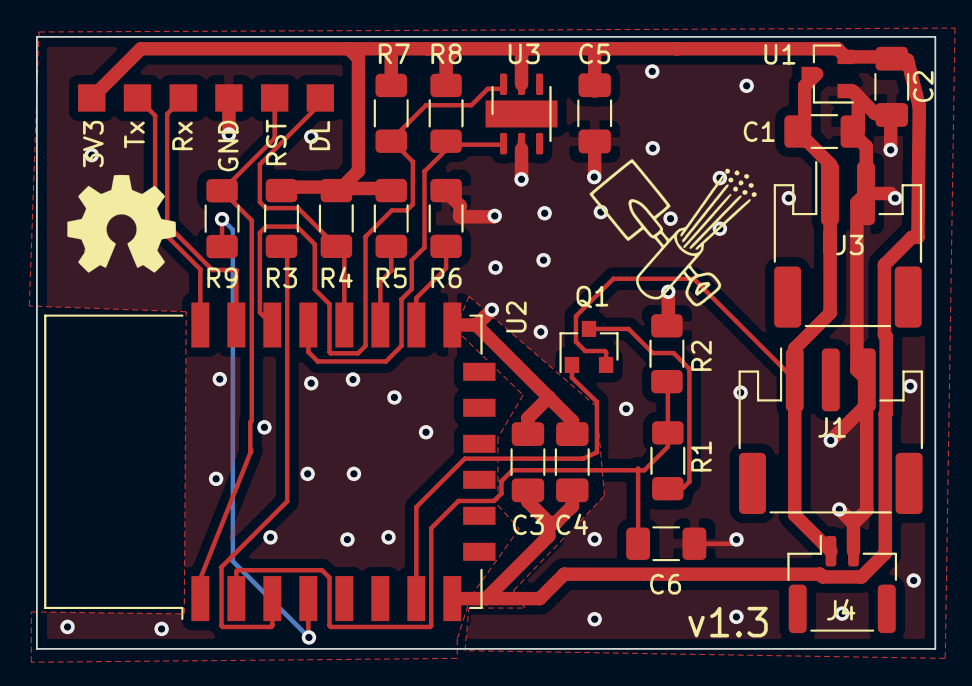
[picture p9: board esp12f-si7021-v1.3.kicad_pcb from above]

Board: 2 copper layers, 49.9 x 34.0 mm, 23 parts (0 on the bottom side), 16 nets.

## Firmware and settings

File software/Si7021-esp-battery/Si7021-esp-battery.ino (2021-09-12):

/*
 * ESP-12F with Si7021 (battery-powered)
 *
 * MQTT Temperature and Humidity Sensor
 *
 * Designed for integration with HomeAssistant
 *
 */

#define debug true // serial output at 74880 baud
#define dhcp true // whether to obtain an IP address (slower) via dhcp

#include <ESP8266WiFi.h>
#include <PubSubClient.h>
#include <Adafruit_Si7021.h>

#include "config.h" // WiFi and device settings

WiFiClient espClient;
PubSubClient client(espClient);
Adafruit_Si7021 sensor = Adafruit_Si7021();

// CRC function used to ensuree data validity
uint32_t calculateCRC32(const uint8_t *data, size_t length);

// helper function to dump memory contents as hex
void printMemory();

// helper function to save memory
void saveMemory();

// Structure which will be stored in RTC memory.
// First field is CRC32, which is calculated based on the
// rest of structure contents.
// Must be 4-byte aligned
struct {
  uint32_t crc32; // 4 bytes
  struct {
    float temperature;    // 4 bytes
    float humidity;       // 4 bytes
    float vbatt;            // 4 bytes
    uint8_t bssid[6];       // 6 bytes
    uint8_t channel;        // 1 byte
    bool publish;           // 1 byte
    bool publishHumidity; // 1 byte
    bool publishVbatt;      // 1 byte
    uint8_t padding[2];   // 2 bytes
  } data;
} rtcData;

bool quickConnect = false; // setting to connect quickly from RTC data
float temperature, humidity;

void setup() {

  if (debug) {
    Serial.begin(74880);
    while (!Serial) {}
    Serial.setDebugOutput(true);
    Serial.println("Starting up");
    Serial.flush();
  }
  
  // switch off WiFi until we need it
  WiFi.mode(WIFI_OFF);
  WiFi.forceSleepBegin();
  delay(1);

  // power down the ADC
  pinMode(adcPowerPin, OUTPUT);
  digitalWrite(adcPowerPin, HIGH); // inverted

  // read RTC memory
  if (ESP.rtcUserMemoryRead(0, (uint32_t*) &rtcData, sizeof(rtcData))) {
    uint32_t crcOfData = calculateCRC32((uint8_t*) &rtcData.data, sizeof(rtcData.data));
    if (crcOfData != rtcData.crc32) {
      if (debug) Serial.println("CRC32 in RTC memory doesn't match CRC32 of data. Data is probably invalid!");
      // take fresh readings
      readAllSensors();
      // flag to publish
      rtcData.data.publish = true;
      rtcData.data.publishHumidity = true;
      rtcData.data.publishVbatt = true;
    } else {
      if (debug) {
        Serial.println("CRC32 check ok, data is probably valid.");
        Serial.print("RTC memory size: ");
        Serial.println(sizeof(rtcData));
        Serial.println();
        Serial.println("Read: ");
        printMemory();
        Serial.println();
        Serial.print("CRC32 of data: ");
        Serial.println(crcOfData, HEX);
        Serial.print("CRC32 read from RTC: ");
        Serial.println(rtcData.crc32, HEX);
        Serial.print("RTC Temperature: ");
        Serial.println(rtcData.data.temperature);
        Serial.print("RTC Humidity: ");
        Serial.println(rtcData.data.humidity);
        Serial.print("RTC Vbatt: ");
        Serial.println(rtcData.data.vbatt);
        Serial.print("RTC WiFi channel: ");
        Serial.println(rtcData.data.channel);
        Serial.print("RTC BSSID: ");
        for (int i=0; i<6; i++) {
          Serial.print(rtcData.data.bssid[i],HEX);
        }
        Serial.println();
        Serial.print("RTC publish: ");
        Serial.println(rtcData.data.publish);
        Serial.print("RTC publish humidity: ");
        Serial.println(rtcData.data.publishHumidity);
        Serial.print("RTC publish vbatt: ");
        Serial.println(rtcData.data.publishVbatt);
      }
      quickConnect = true;
    }
  } else {
    if (debug) Serial.println("Failed to read from memory");
    // take fresh readings
    readAllSensors();
    // flag to publish
    rtcData.data.publish = true;
    rtcData.data.publishHumidity = true;
    rtcData.data.publishVbatt = true;
  }

  // we should have RF, and have been asked to publish
  if (rtcData.data.publish) {

    if (debug) {
      Serial.println("Publishing:");
      Serial.print("Temperature: ");
      Serial.println(rtcData.data.publish); // should always be true
      Serial.print("Humidity: ");
      Serial.println(rtcData.data.publishHumidity);
      Serial.print("Vbatt: ");
      Serial.println(rtcData.data.publishVbatt);
      Serial.println();
      Serial.print("Connecting to ");
      Serial.println(wifi_ssid);
    }

    // minimise WiFi cycle as much as possible

    WiFi.forceSleepWake();
    delay(1);

    WiFi.persistent(false);

    // Bring up the WiFi connection
    WiFi.mode(WIFI_STA);

    // Static IP assignment
    if (!dhcp) WiFi.config(ip,gateway,subnet);

    WiFi.hostname(wifi_hostname);

    if (quickConnect) {
      if (debug) Serial.println("Quick connect");
      WiFi.begin( wifi_ssid, wifi_password, rtcData.data.channel, rtcData.data.bssid, true );
    } else {
      if (debug) Serial.println("Standard connect");
      WiFi.begin(wifi_ssid, wifi_password);
    }

    int count = 0;
    while (WiFi.status() != WL_CONNECTED) {
      if (count > 150) { // 15 seconds
          if (debug) {
            Serial.println("WiFi connection timeout, dropping back into deep sleep");
            Serial.print("WiFi status code: ");
            Serial.println(WiFi.status());
            int n = WiFi.scanNetworks(false, true);
            Serial.print(n);
            Serial.println(" WiFi network(s) detected");
          }
          // go back to sleep and try again when woken up
          ESP.deepSleepInstant(polling_us, WAKE_RF_DEFAULT ); // in uS
      }
      delay(100);
      if (debug) Serial.print(".");
      count++;
    }

    if (debug) {
      Serial.println("");
      Serial.println("WiFi connected");
      Serial.println("IP address: ");
      Serial.println(WiFi.localIP());
      Serial.println();
      Serial.println("MAC address: ");
      Serial.println(WiFi.macAddress());
      Serial.println();
    }

    client.setServer(mqtt_server, 1883);

    if (!client.connected()) {
      if (debug) Serial.print("Attempting MQTT connection...");
      if (client.connect("ESP8266Client")) {
        if (debug) Serial.println("connected");
      } else {
          if (debug) {
            Serial.print("failed, rc=");
            Serial.print(client.state());
            Serial.println(" going back to sleep to try again later");
          }
          // go back to sleep and try again when woken up
          ESP.deepSleepInstant(polling_us, WAKE_RF_DEFAULT ); // in uS
      }
    }

    // publish requested data
    client.publish(temperature_topic, String(rtcData.data.temperature).c_str(), true);
    if (rtcData.data.publishHumidity) client.publish(humidity_topic, String(rtcData.data.humidity).c_str(), true);
    if (rtcData.data.publishVbatt) client.publish(vbatt_topic, String(rtcData.data.vbatt).c_str(), true);

    client.disconnect();

    // always store BSSID and channel in case device hops APs
    rtcData.data.channel = WiFi.channel();
    memcpy( rtcData.data.bssid, WiFi.BSSID(), 6 ); // Copy 6 bytes of BSSID (AP's MAC address)
    if (debug) {
      Serial.print("Storing BSSID: ");
      for (int i=0; i<6; i++) {
        Serial.print(rtcData.data.bssid[i],HEX);
      }
      Serial.println();
      Serial.print("Storing channel: ");
      Serial.println(rtcData.data.channel);
    }

    // update values
    rtcData.data.publish = false;
    rtcData.data.publishHumidity = false;
    rtcData.data.publishVbatt = false;

    saveMemory();

    if (debug) Serial.println("Publishing complete, going to RF deep sleep");

    ESP.deepSleepInstant(polling_us, WAKE_RF_DISABLED ); // in uS

  } else { // check to see if we need to publish due to temp change

    readSi7021();

    float tempDifference = fabs(temperature - rtcData.data.temperature);
    if (debug) {
      Serial.print("Temperature difference: ");
      Serial.println(tempDifference);
    }

    if (tempDifference > temperatureChangeThreshold) {
      if (debug) Serial.println("Temperature change detected, flagging to publish");
      rtcData.data.publish = true;
      rtcData.data.temperature = temperature;
    } else {
      if (debug) Serial.println("No significant temperature change detected, skipping");
    }

    // only check other readings if temperature is going to be published
    if (rtcData.data.publish) {
      float humidityDifference = fabs(humidity - rtcData.data.humidity);

      if (debug) {
        Serial.print("Humidity difference: ");
        Serial.println(humidityDifference);
      }

      if (humidityDifference > humidityChangeThreshold) {
        if (debug) Serial.println("Humidity change detected, flagging to publish");
        rtcData.data.publishHumidity = true;
        rtcData.data.humidity = humidity;
      } else {
        if (debug) Serial.println("Skipping humidity publication");
      }

      float vbatt = readVbatt();
      float vbattDifference = fabs(rtcData.data.vbatt-vbatt);

      if (debug) {
        Serial.print("Vbatt difference: ");
        Serial.println(vbattDifference);
      }

      // prepare to publish vcc
      if (vbattDifference >= 0.01) {
        if (debug) Serial.println("Vbatt change detected; will publish");
        rtcData.data.publishVbatt = true;
        rtcData.data.vbatt = vbatt;
      } else {
        if (debug) Serial.println("Skipping Vbatt publication");
      }

      saveMemory();

      // reset with rf enabled
      ESP.deepSleepInstant(1000, WAKE_RF_DEFAULT ); // in uS

    }  else {// end if temp will be published

      if (debug) Serial.println("No change detected, going back to sleep");

      ESP.deepSleepInstant(polling_us, WAKE_RF_DISABLED ); // in uS

    } // end no publication

  } // end check if temp will be published
  
} // end setup

void loop() {
} // end loop

// calculate checksum of struct
uint32_t calculateCRC32(const uint8_t *data, size_t length) {
  uint32_t crc = 0xffffffff;
  while (length--) {
    uint8_t c = *data++;
    for (uint32_t i = 0x80; i > 0; i >>= 1) {
      bool bit = crc & 0x80000000;
      if (c & i) {
        bit = !bit;
      }
      crc <<= 1;
      if (bit) {
        crc ^= 0x04c11db7;
      }
    }
  }
  return crc;
}

//prints all rtcData, including the leading crc32
void printMemory() {
  char buf[3];
  uint8_t *ptr = (uint8_t *)&rtcData;
  for (size_t i = 0; i < sizeof(rtcData); i++) {
    sprintf(buf, "%02X", ptr[i]);
    Serial.print(buf);
    if ((i + 1) % 32 == 0) {
      Serial.println();
    } else {
      Serial.print(" ");
    }
  }
  Serial.println();
} // end printMemory

// save data to rtc
void saveMemory() {
  // Update CRC32 of data
  rtcData.crc32 = calculateCRC32((uint8_t*) &rtcData.data, sizeof(rtcData.data));
  // Write struct to RTC memory
  if (ESP.rtcUserMemoryWrite(0, (uint32_t*) &rtcData, sizeof(rtcData))) {
    if (debug) {
      Serial.println("Wrote: ");
      printMemory();
      Serial.println();
      Serial.print("Temperature: ");
      Serial.println(rtcData.data.temperature);
      Serial.print("Humidity: ");
      Serial.println(rtcData.data.humidity);
      Serial.print("Vbatt: ");
      Serial.println(rtcData.data.vbatt);
      Serial.print("Publish: ");
      Serial.println(rtcData.data.publish);
      Serial.print("Publish humidity: ");
      Serial.println(rtcData.data.publishHumidity);
      Serial.print("Publish vbatt: ");
      Serial.println(rtcData.data.publishVbatt);
    }
  } else {
    if (debug) Serial.println("Failed to write to memory");
  }

} // end saveMemory

// read voltage of battery
float readVbatt() {

    if (debug) {
      Serial.println("Measuring battery voltage");
    }

    // switch on ADC circuit
    digitalWrite(adcPowerPin, LOW); // inverted

    if (debug) {
      Serial.println("ADC voltage enabled for 3s");
      delay(3000);
    }

    // first adc reading is garbage, so take another
    int adc = analogRead(A0);
    adc = analogRead(A0);
    if (debug) {
      Serial.print("ADC reading: ");
      Serial.println(adc);
    }
    
    // switch off ADC circuit
    digitalWrite(adcPowerPin, HIGH); // inverted

    if (debug) {
      Serial.println("ADC voltage disabled for 3s");
      delay(3000);
    }

    float vbatt = vbatt_calibration * float(adc);

    if (debug) {
      Serial.print("Vbatt: ");
      Serial.println(vbatt);
    }

    return vbatt;
} // end readVbatt

// read all sensors and store in rtcData
void readAllSensors() {
    readSi7021();
    // store in RTC variables
    rtcData.data.temperature = temperature;
    rtcData.data.humidity = humidity;
    rtcData.data.vbatt = readVbatt();
} // end readAllSensors

// read Si7021 chip using Adafruit library
void readSi7021() {

  // allow the Si7021 sensor time to wake up
  if (!sensor.begin()) {
    if (debug) Serial.println("Did not find Si7021 sensor! Crashing now...");
    while (true)
      ; // causes a crash/reboot
  }

  if (debug) {
    Serial.print("Found model ");
    switch(sensor.getModel()) {
      case SI_Engineering_Samples:
        Serial.print("SI engineering samples"); break;
      case SI_7013:
        Serial.print("Si7013"); break;
      case SI_7020:
        Serial.print("Si7020"); break;
      case SI_7021:
        Serial.print("Si7021"); break;
      case SI_UNKNOWN:
      default:
        Serial.print("Unknown");
    }
    Serial.print(" Rev(");
    Serial.print(sensor.getRevision());
    Serial.print(")");
    Serial.print(" Serial #"); Serial.print(sensor.sernum_a, HEX); Serial.println(sensor.sernum_b, HEX);
  }
  
  // read latest sensors
  humidity = sensor.readHumidity();
  temperature = sensor.readTemperature();

  if (debug) {
    Serial.print("Reading temperature: ");
    Serial.println(temperature);
    Serial.print("Reading humidity: ");
    Serial.println(humidity);
  }

} // end readSi7021

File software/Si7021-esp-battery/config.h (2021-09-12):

// Device name
#define device "device" // will prefix later parameters

// WiFi credentials.
#define wifi_hostname device "-sensor"
#define wifi_ssid "SSID"
#define wifi_password "PASSPHRASE"
// Once you have a static IP, enter it below
IPAddress ip(0,0,0,0);
IPAddress gateway(0,0,0,0);
IPAddress subnet(255,255,255,0);

// Sensor configuration
#define temperatureChangeThreshold 0.08 // repeatability from the data sheet
#define humidityChangeThreshold 0.2 // repeatability from the data sheet
#define adcPowerPin 13 // GPIO13 for ADC
// Ideal ADC and voltage divider behaviour
// is 4.2/1024.0
// For accurate battery voltage measurements
// use an accurate voltage input, measure ADC
// and replace values below (assumes linear response)
#define vbatt_calibration 4.2/1024.0

// Reporting
#define polling_m 10 // every X minutes
#define polling_s polling_m * 60
#define polling_ms polling_s * 1000
#define polling_us polling_ms * 1000
#define mqtt_server "0.0.0.0"
#define humidity_topic device "/humidity"
#define temperature_topic device "/temperature"
#define vbatt_topic device "/vbatt"

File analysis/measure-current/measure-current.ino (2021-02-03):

#include <Adafruit_INA260.h>

Adafruit_INA260 ina260 = Adafruit_INA260();

unsigned long timestamp;

void setup() {
  Serial.begin(115200);
  // Wait until serial port is opened
  while (!Serial) { }
  Serial.println("Looking for INA260 chip");
  if (!ina260.begin()) {
    Serial.println("Couldn't find INA260 chip");
    while (1);
  }
  Serial.println("Found INA260 chip");
  Serial.println("timestamp,current,voltage");
}

void loop() {
  Serial.print(millis());
  Serial.print(",");
  Serial.print(ina260.readCurrent());
  Serial.print(",");
  Serial.print(ina260.readBusVoltage());
  Serial.println();
}

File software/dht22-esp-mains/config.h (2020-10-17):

// Device name
#define device "device" // will prefix later parameters

// WiFi credentials.
#define wifi_hostname device "-sensor"
#define wifi_ssid "SSID"
#define wifi_password "PASSPHRASE"

// Sensor configuration
#define dhtDataPin 14 // GPIO14 / D5 on nodemcu
#define dhtPowerPin 12 // GPIO12 / D6 on nodemcu
#define dhtTemperatureChangeThreshold 0.2 // repeatability from the data sheet
#define dhtHumidityChangeThreshold 1 // repeatability from the data sheet

// Reporting
#define polling_m 1 // every X minutes
#define polling_s polling_m * 60
#define polling_ms polling_s * 1000
#define mqtt_server "0.0.0.0"
#define humidity_topic device "/humidity"
#define temperature_topic device "/temperature"

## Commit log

2020-10-17 Fresh commit
    [data.csv, esp12f-dht22.kicad_pcb, esp12f-dht22.sch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]
2020-11-24 Add batteries and connectors
2020-11-24 Highlight selected power components
2021-02-03 Update to v1.1
    [esp12f-dht22.kicad_pcb, esp12f-dht22.sch, esp12f-si7021.kicad_pcb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]
2021-02-03 Remove dht22-battery
2021-02-22 Add v1.2 hardware design. Closes #2.
    [esp12f-si7021-B_Cu.gbr, esp12f-si7021-B_Mask.gbr, esp12f-si7021-B_SilkS.gbr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]
2021-02-22 Add paste layer
    [esp12f-si7021.kicad_pcb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]
2021-03-21 Add case, analysis
    [avg.csv, case.scad, case_with_lid.scad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]
2021-04-05 Refine Vbatt sensor
2021-04-05 Add BOM
    [esp12f-si7021_bom.csv]
2021-04-28 Case v2
    [case_with_lid.scad, case_with_lid.stl]
2021-04-28 add note
    [case_with_lid.scad]
2021-05-17 Tweak adc performance
2021-05-17 Cleanup assets
    [case.scad, case_with_lid.scad, esp12f-si7021.kicad_pcb]
2021-09-12 Add ADC calibration sketch and details
2021-09-12 v1.3 - pogo pins and more. See #4
    [esp12f-si7021-B_Cu.gbr, esp12f-si7021-B_Mask.gbr, esp12f-si7021-B_SilkS.gbr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]
2021-09-12 Tweak positioning of programming header
    [esp12f-si7021-v1.3.kicad_pcb]
2021-09-19 Tweak resistor values
    [esp12f-si7021-v1.3.sch]
